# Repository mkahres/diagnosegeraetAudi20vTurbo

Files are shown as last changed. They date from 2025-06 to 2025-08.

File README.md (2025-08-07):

# Audi 20V Turbo Diagnosegerät (Bosch Motronic)

Das ist ein Diagnosegerät zum selber bauen. Es passt ins Handschuhfach, ist benutzerfreundlich und komplett Open Source. Für genauere Analysen gibts noch ein auf die 10 Sensorwerte angepasstes Auswertungstool dazu.

🔽 [aktuelle ZIP-Datei herunterladen (Version 1.1.2)](https://github.com/mkahres/diagnosegeraetAudi20vTurbo/archive/refs/heads/master.zip)

<table>
  <tr>
    <td></td>
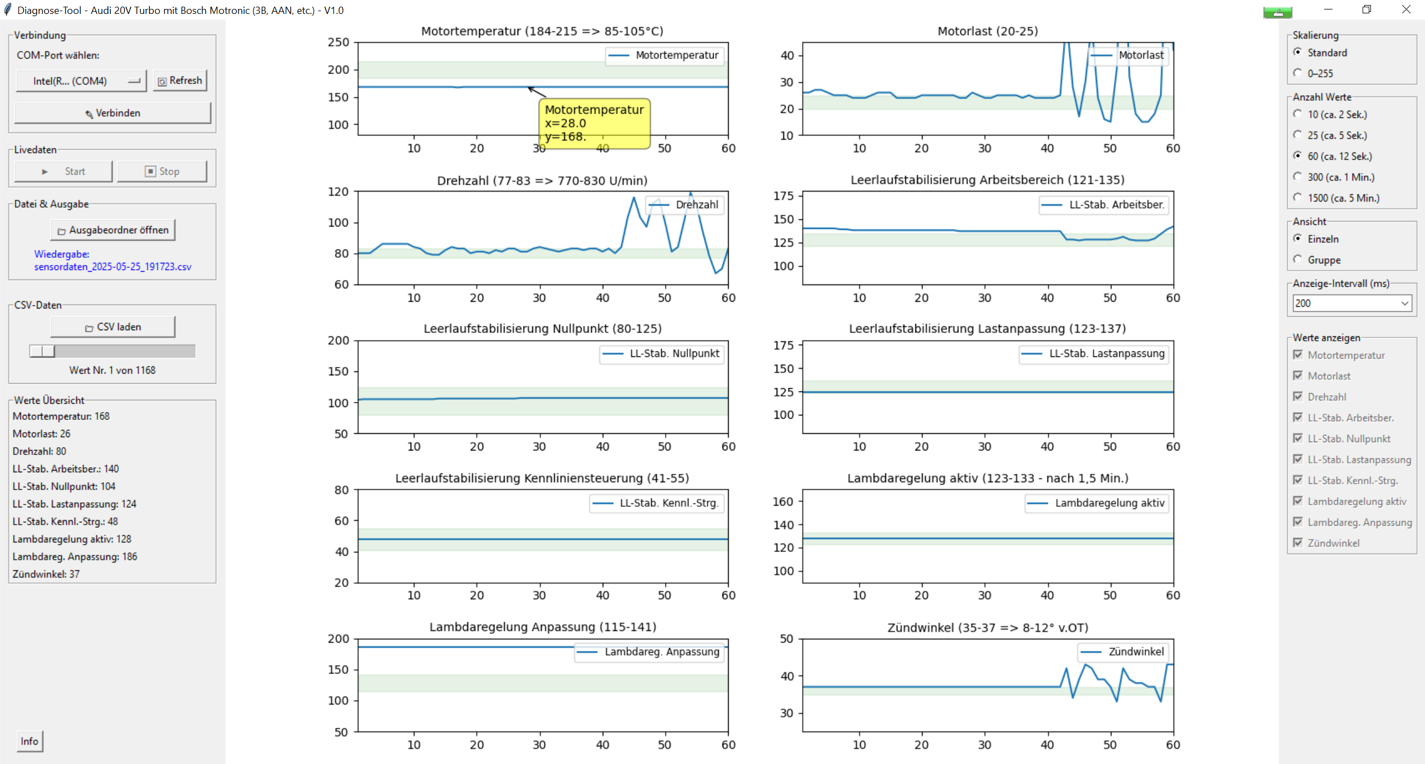
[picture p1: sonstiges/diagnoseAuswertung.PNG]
    <td></td>
  </tr>
</table>

---

## 📲 Bedienung und Infos zum Nachbauen

youtube-Video: [https://www.youtube.com/watch?v=6eNAYaNCjRk](https://www.youtube.com/watch?v=dj4Saa1aYWg)

Bei Fragen kommentiert am besten unter dem Video oder legt hier einen Issue an.

- Gerät startet sobald es am Diagnosestecker am Auto eingesteckt wird (auch ohne Zündung).
- Um die Sensorwerte über das Auswertungsprogramm zu analysieren wird zusätzlich der Laptop per USB an das Diagnosegerät angeschlossen.
- Das Diagnosegerät kann auch allein über USB am Laptop betrieben werden um sich die gespeicherten Fehler/Sensorwerte anzugucken. Das Easteregg funktioniert auch über USB.
- ⚠️ Auf keinen Fall das Gerät an den Diagnosestecker und zusätzlich am Zigarettenanzünder per USB-Adapter anschließen, evtl. gibt es dann ein Masse-Problem!?
- ⚠️ Das Auswertungstool wurde nur auf Laptops mit Windows 10 und 11 getestet. Um es auf Mac/Linux zum Laufen zu bringen sollte man sich schon etwas mit Python auskennen!

---

## 🔧 Funktionen

- ✅ **Fehlerspeicher auslesen über K-Line**
- ✅ **Fehlerspeicher ausblinken**
- ✅ **Fehlerspeicher löschen über K-Line oder am Ende der Blinkcode-Stellglieddiagnose**
- ✅ **Stellglieddiagnose über K-Line**
- ✅ **Stellglieddiagnose mit Blinkcode**
- ✅ **Sensorwerte live auslesen**
- ✅ **Speichern & Laden von Sensordaten und Fehlerspeicher**
- ✅ **Stromversorgung über Diagnosestecker im Auto**
- ✅ **Das zusätzliche Auswertungstool erlaubt genauere Betrachtung der Diagnosewerte über Laptop**
- 🐣 **Easteregg inklusive 😎**

---

## 🚗 Unterstützte Fahrzeuge

Ich habe es nur an meinem Audi 200 20V getestet, daher keine Garantie! Da sich die Steuergeräte nach meinem Kenntnisstand in Bezug auf die Auslesefunktionen bei diesen Motoren nicht unterscheiden, dürfte es bei folgenden Fahrzeugen problemlos funktionieren:
- **Audi 200 20V (3B)**
- **Audi S2 (3B)**
- **Audi S4 / S6 C4 (AAN)**
- **Audi Urquattro 20V (RR)**

vermutlich eingeschränkt verwendbar:
- **20V Turbos mit ABY, ADU, etc.:**
Hier können wohl mehr als 10 Sensoren ausgelesen werden. Dies ist mit dem Tool aktuell nicht möglich. Falls jemand Bock hat, die verwendete Library KLineKWP1281Lib unterstützt das Auslesen sämtlicher Gruppen. Es wäre also theoretisch möglich das Tool zu erweitern. Evtl. gibt es bei den Motoren auch mehr Fehlercodes und andere Fehlertexte.

mit kleinen Änderungen verwendbar:
- **Audi 100/200 (NF/MC und andere):**
bei den Motoren die nur das Ausblinken unterstützen muss die Hardware etwas geändert werden. Außerdem sind kleine Anpassungen in der Software-Konfiguration notwendig (siehe [Anmerkungen](#-anmerkungen))

---

## ⚡ Schaltplan

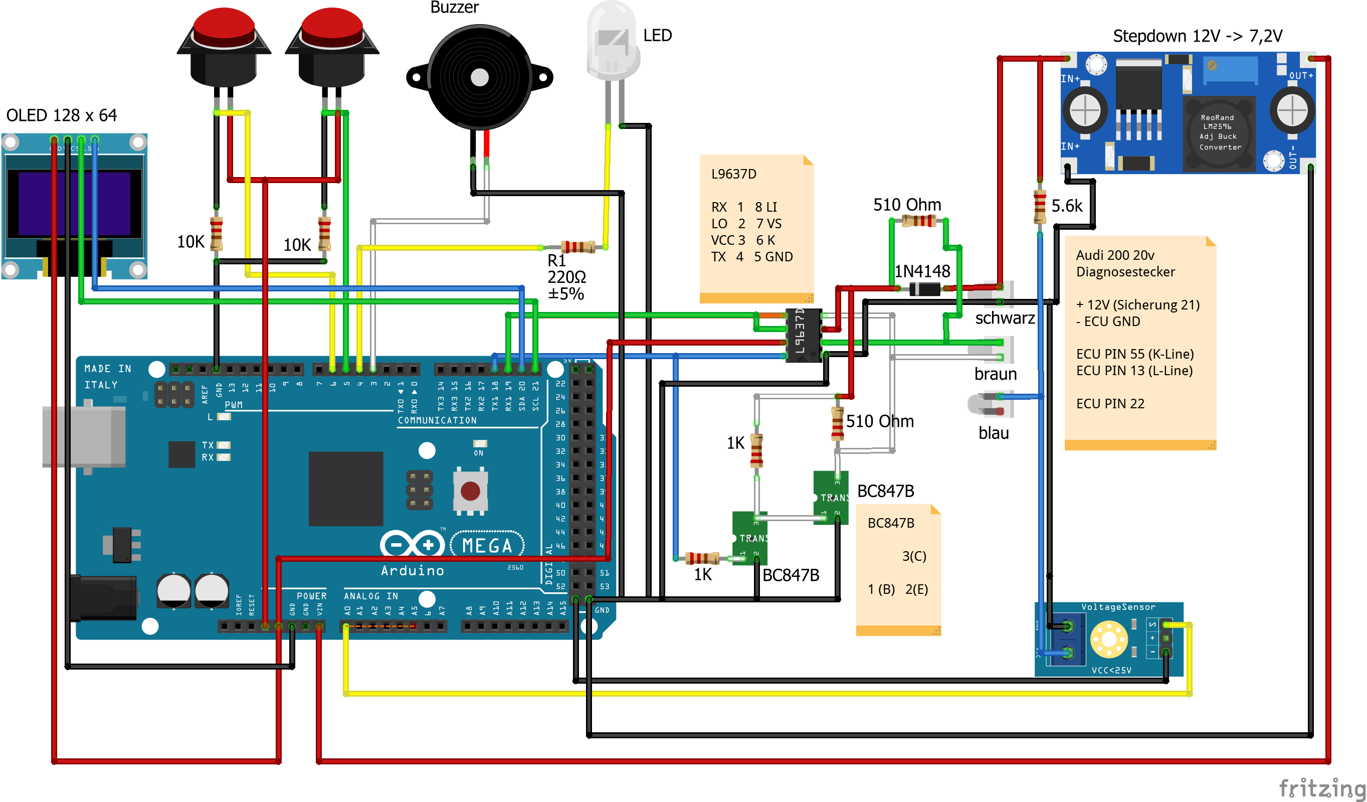
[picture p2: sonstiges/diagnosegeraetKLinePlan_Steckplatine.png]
Schaltplan Vorschau


Unter /sonstiges findet man ein paar Bilder vom Zusammenbau.

---

## 🧱 3D Druck

Den 3D-Druck sollte man am besten mit PETG machen, da es im Hochsommer evtl. doch mal über 60 Grad im Auto werden können und PLA dann schmilzt. Die Dateien liegen unter /stl 

---

## 🖥️ Setup & Upload

Alles nur auf Windows getestet. Gerade das Python Tool könnte auf Mac und Linux Probleme machen!

**Arduino**
- aktuelle Arduino IDE installieren: https://www.arduino.cc/en/software/
- den Sketch (/diagnoseGeraet/diagnoseGeraet.ino) in der IDE öffnen
- folgende Libraries über den Library Manager installieren (https://docs.arduino.cc/software/ide-v1/tutorials/installing-libraries/#using-the-library-manager):
   - Adafruit_SH110X
   - U8g2_for_Adafruit_GFX
- die Library KLineKWP1281Lib von dieser Seite herunterladen (unter Getting started - latest Release) https://github.com/domnulvlad/KLineKWP1281Lib/tree/main und als ZIP-Library einbinden (siehe hier: https://docs.arduino.cc/software/ide-v1/tutorials/installing-libraries/#importing-a-zip-library)
- Board und Port auswählen und den Sketch über den Upload-Button auf den Arduino laden (https://support.arduino.cc/hc/en-us/articles/4733418441116-Upload-a-sketch-in-Arduino-IDE)

**Python**  
- aktuelles Python Release installieren für das Auswertungs-Tool: https://www.python.org/downloads/
- Während der Installation wird gefragt ob man Python zum PATH hinzufügen will, das sollte man tun.
- Falls Microsoft Visual C++ Redistributable noch nicht installiert ist, bitte ebenfalls installieren:
  - https://learn.microsoft.com/de-de/cpp/windows/latest-supported-vc-redist?view=msvc-170
  - https://aka.ms/vs/17/release/vc_redist.x64.exe
  - https://aka.ms/vs/17/release/vc_redist.x86.exe
- Doppelklick auf /diagnoseAuswertung/startTool_Windows.bat zum Starten des Tools

---

## 🛒 Einkaufsliste

- Arduino Mega oder Clone (hier wurde ein Elegoo Mega verwendet)
- L9637D I/O-Controller-IC-Interface
- 1,3 Zoll OLED Display (mit 0,96 Zoll funktioniert der Code nicht, da das eine andere Library benötigt!)
- 2x Diagnose Adapterkabel 2x2 OBD
- 5-adriges Kabel vom Diagnosestecker zum Tool
- 2x JST SM Stecker für Verbindung Adapterkabel -> 5-adriges Kabel -> Arduino
- Gummitülle für das Kabel das ins Gehäuse geht
- LM2596S Step Down Converter
- Spannungssensor DC 0~25V
- LED ⌀ 3mm
- 2x Push Button 12mm mit Mutter
- passiver Buzzer
- 2x Widerstand 510 Ω (L9637d Spezifikation - bitte genau daran halten)
- 2x Widerstand 1K Ω
- 2x Widerstand 10K Ω
- 1x Widerstand 5.6k Ω
- 1x Widerstand 220 Ω
- Diode 1N4148
- 2x Transistor BC847B
- viele Jumperkabel und -stecker
  
Folgende Teile fand ich hilfreich, damit passt dann alles in das kleine Gehäuse rein.
- SOT23 Adapterplatine (für die Transistoren)
- Adafruit SMT Breakout Leiterplatte für SOIC-8 (für den L9637D)
- EPLZON Prototype Board 2 x 1,5 Zoll (da hab ich dann die Platinen, die Widerstände und die Diode draufgelötet)

Für Fahrzeuge die nur das Ausblinken unterstützen braucht man anstatt des L9637D, den Transistoren, Widerständen usw. nur ein Relais
- z.B. AZDelivery KY-019

---

## 📌 Anmerkungen

**Ausblinken mit Relais für NF, MC etc.** 

Für Motoren ohne K-Line Schnittstelle die nur Ausblinken unterstützen muss statt des L9637D ein Relais verwendet werden um die Drahtbrücke zu schließen. Die Verkabelung für den Spannungsmesser um die Blinkcodes zu erkennen muss dann auch geändert werden. 
Fehlercodes und -texte sind für NF und MC bereits im Code hinterlegt. Man muss nur die Konfiguration in der Datei "Constants.h" anpassen:

<pre>const char ENGINE = "3B"; //mögliche Werte: "3B", "MC", "NF"  - für RR, AAN, etc. verwende "3B"
#define USE_RELAIS false //für MC, NF, etc. auf true setzen
#define PIN_RELAY 12 //für MC, NF, etc. den Relais PIN setzen</pre>

**Ausblinken beim 20v Turbo**

Die Ausblinkfunktion wird beim 20v Turbo über den L9637D gesteuert. Theoretisch ist das Ausblinken für den 20V gar nicht notwendig, da alle Funktionen über K-Line verfügbar sind. Wenn man darauf verzichten will kann man folgende Teile weglassen:
- Spannungsmesser
- von den Diagnoseadapter-Kabeln 2x2 braucht man nur noch einen Satz, da dann der blaue Stecker nicht mehr verwendet wird  
- LED weglassen oder besser immer auf an setzen. Dazu in diagnoseGeraetAudi200.ino irgendwo in der Funktion setup() diese Zeile hinzufügen: <pre>analogWrite(ledPin, 5);</pre>

**Debugging** 

Sollte es Probleme bei der K-Line Kommunikation geben kann man in configuration.h das Debugging aktivieren (beide Werte auf "true"). Das sollte man nur zum Testen einschalten, da die Debugging-Ausgaben die Kommunikation mit dem Auswertungstool behindern.

<pre>// Enable/disable printing library debug information on the Serial Monitor.
// You may change the debug level in "KLineKWP1281Lib.h".
#define debug_info false
// Enable/disable printing bus traffic on the Serial Monitor.
#define debug_traffic false</pre>

**Stromversorgung**

Die Versorgung erfolgt über einen Step-Down-Regler, der auf 7,2 V eingestellt ist. Am VIN-Pin des Arduino übernimmt der interne Spannungsregler die Absenkung auf 5 V. Damit dieser zuverlässig arbeitet, sollten mindestens 7 V anliegen. Während das Original (7–12 V) stabil läuft, lieferte ein Elegoo-Clone bei 9 V Eingang ca. 6 V am 5 V-Pin. Mit 7,2 V bekommt man aber dann sichere 5 V.

---

## 📦 Inhalte hier auf GitHub

- `diagnoseGeraet/` → Arduino-Sketch zum Upload auf den Arduino
- `diagnoseAuswertung/` → Python-Tool zur Anzeige und Speicherung von Sensorwerten (Live & CSV)
- `sonstiges/` → Fritzing-Schaltplan und Bilder 
- `stl/` → Dateien für den 3D-Druck

---

## ⚠️ Haftungsausschluss

Dieses Projekt wird ohne jegliche Garantie zur Verfügung gestellt. Die Nutzung erfolgt auf eigene Gefahr. Der Autor übernimmt keine Haftung für Schäden an Fahrzeugen, Steuergeräten oder anderen Komponenten, die durch den Einsatz der bereitgestellten Hardware oder Software entstehen können.

---

## 👍 Danke!

- https://www.blafusel.de/obd/obd2_kw1281.html#5 (sehr gute Beschreibung der K-Line Kommunikation)
- https://github.com/domnulvlad/KLineKWP1281Lib/tree/main (sehr gute Library, damit konnte ich alle Funktionen umsetzen)
- https://www.drive2.ru/c/2032328 (ein Teil des Schaltplans stammt von dieser Seite)
- http://www.audinarren.de/rep-Anleitung/fehlerspeicher.htm (Fehlertexte in Kurz- und Langform)
- http://www.sjmautotechnik.com/trouble_shooting/20vpin.html (viele Infos incl. Pin-Belegung)
- Scheiß-KI die besser mit Python programmieren kann als ich
- und vielen Dank an die Forumsmitglieder von [forum.group44.de ](https://forum.group44.de/), vor allem an BAUM4477 für die ganzen hilfreichen Tipps!
---

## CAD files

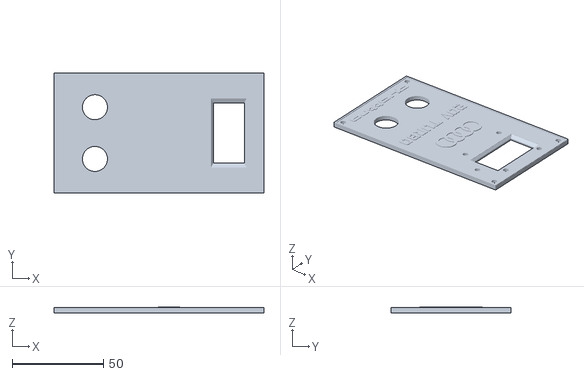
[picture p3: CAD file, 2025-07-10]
stl/Deckel_20v_Turbo.stl
115.1 x 66.0 x 3.20

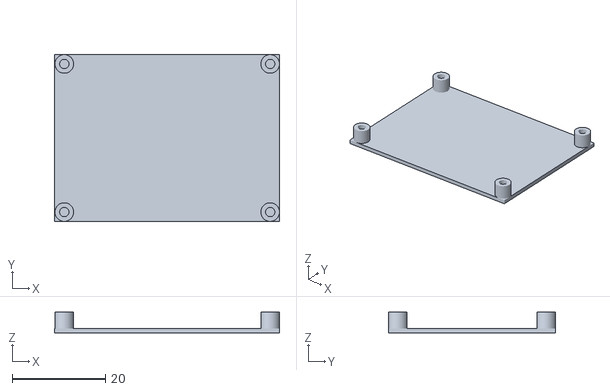
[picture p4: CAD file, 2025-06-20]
stl/Halterung_PrototypeBoard.stl
48.3 x 35.9 x 4.50

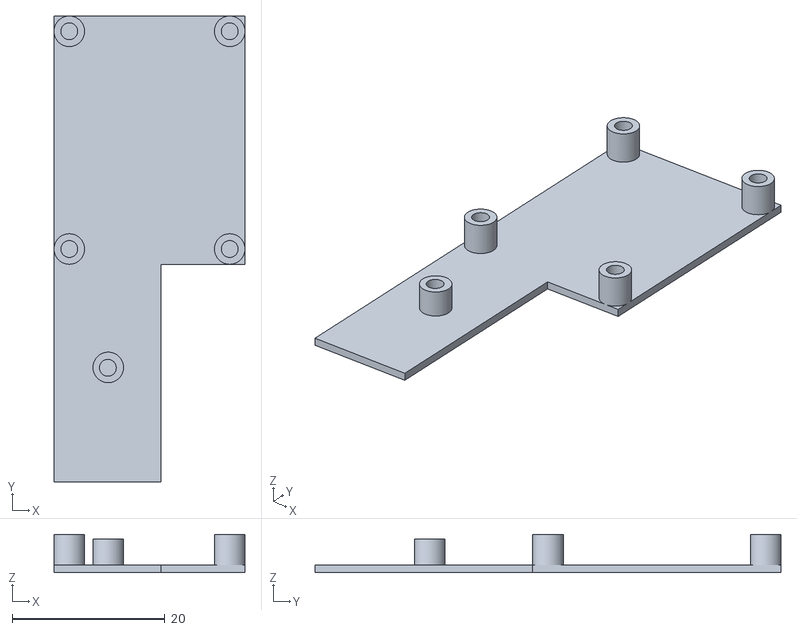
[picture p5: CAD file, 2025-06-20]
stl/Halterung_Spannungssensor_und_Relais.stl
25.0 x 61.0 x 5.00

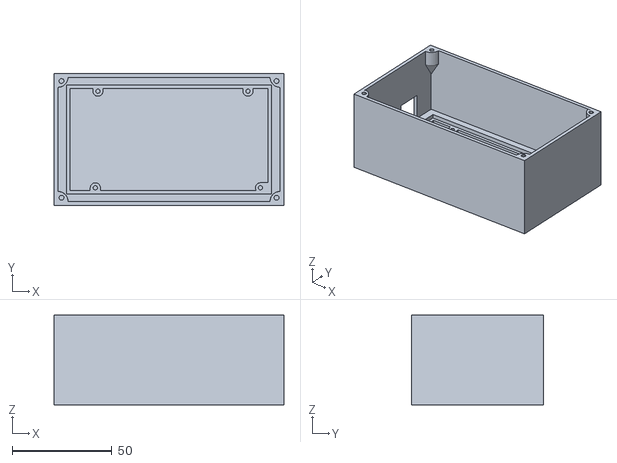
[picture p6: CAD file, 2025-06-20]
stl/Gehaeuse.stl
115.0 x 66.0 x 44.9

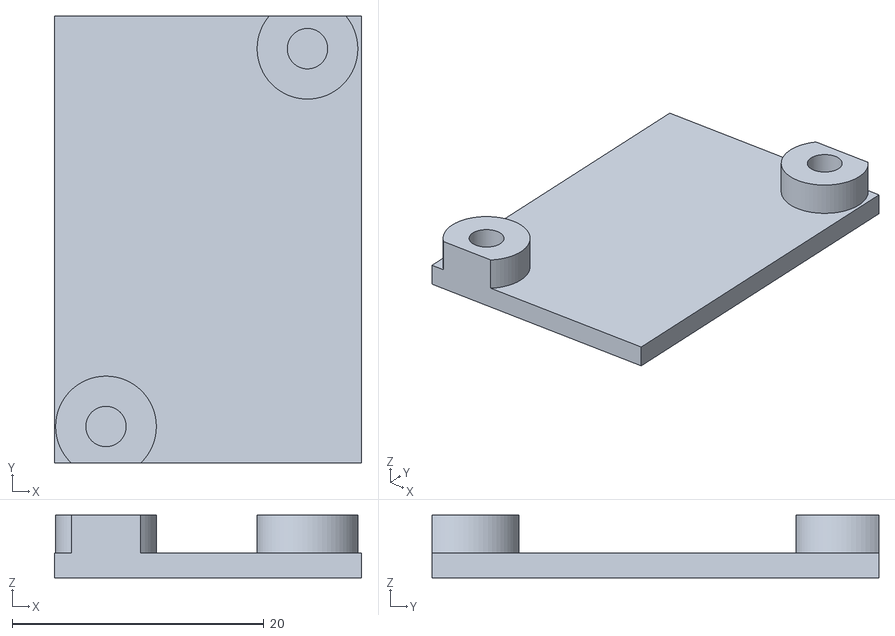
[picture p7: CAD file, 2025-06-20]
stl/Halterung_LM2596S.stl
24.4 x 35.5 x 5.00

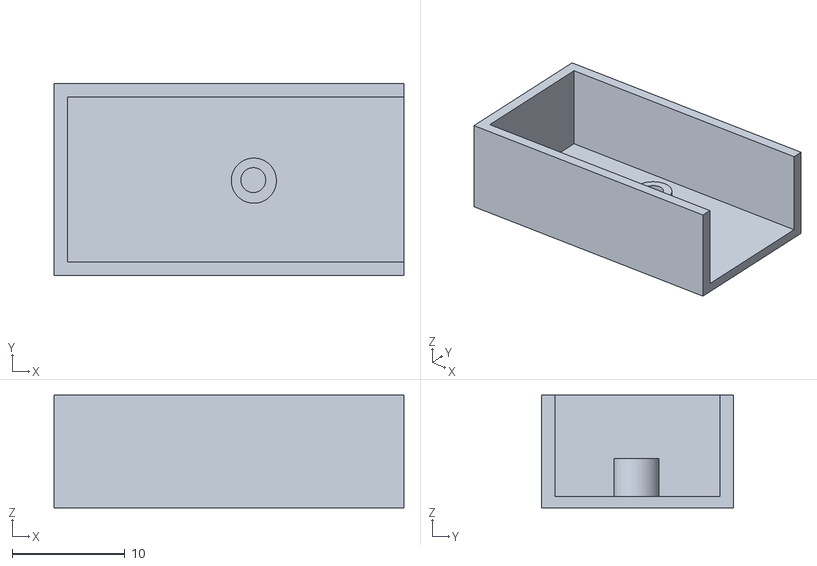
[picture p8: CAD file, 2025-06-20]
stl/Halterung_Spannungssensor.stl
31.0 x 17.0 x 10.00

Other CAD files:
stl/Deckel_200_20v.stl

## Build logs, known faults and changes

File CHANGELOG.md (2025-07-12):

# Changelog

## [1.1.2] – 2025-07-12
- Auswertungstool nun auch mit Windows 11 kompatibel
  
## [1.1.1] – 2025-07-10
- STL für alternativen Deckel (20v Turbo) hinzugefügt
- bessere Bilder vom Inneren des Geräts
- Fehler bei Motorkonfiguration behoben
- Fehler bei wiederholtem Fehlerspeicher ausblinken behoben
  
## [1.1.0] – 2025-07-07
- neue Funktion: optionales Fehlerspeicher löschen am Ende der Stellglieddiagnose per Blinkcode
  
## [1.0.1] – 2025-07-04
- Fehler im Schaltplan korrigiert. Der 1k Widerstand zum zweiten Transistor war falsch verdrahtet.

## [1.0.0] – 2025-06-20
- Erstveröffentlichung

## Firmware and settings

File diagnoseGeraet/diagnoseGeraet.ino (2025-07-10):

#include "Constants.h"
#include "configuration.h"
#include "DisplayManager.h"
#include "MusicManager.h"
#include "MemoryManager.h"
#include "KLineManager.h"
#include "ErrorManager.h"
#include "CrashyBird.h"

DisplayManager displayManager;
MusicManager musicManager;
MemoryManager memoryManager;
KLineManager kLineManager;
ErrorManager errorManager;
CrashyBird crashyBird;

//for memory check
#ifdef __arm__
// should use uinstd.h to define sbrk but Due causes a conflict
extern "C" char* sbrk(int incr);
#else  // __ARM__
extern char *__brkval;
#endif  // __arm__

Adafruit_SH1106G display(SCREEN_WIDTH, SCREEN_HEIGHT, &Wire, OLED_RESET);
U8G2_FOR_ADAFRUIT_GFX u8g2_for_adafruit_gfx;

long currentMillis = 0;
long measureTime = 0;
int voltageBoundary = 7;
boolean isBlinking = false;
long lastBlinkingChange = 0;
long lastInterval = 0;
long voltageTime = 0;

uint8_t START_SCREEN = 0;
uint8_t SELECT_OPERATION = 1;
uint8_t SELECT_MODE = 2;
uint8_t LOAD_FAULT_MEMORY_FAST = 7;
uint8_t LOAD_FAULT_MEMORY_BLINK = 8;
uint8_t LOAD_SENSOR_DATA = 10;
uint8_t PREPARE_FAULT_MEMORY_FAST = 11;
uint8_t PREPARE_FAULT_MEMORY_BLINK = 12;
uint8_t PREPARE_ACTUATOR_DIAGNOSTICS_1 = 13;
uint8_t PREPARE_ACTUATOR_DIAGNOSTICS_2 = 14;
uint8_t EXECUTE_FAULT_MEMORY_FAST = 15;
uint8_t EXECUTE_FAULT_MEMORY_BLINK = 16;
uint8_t ANALYZE_FAULT_MEMORY_BLINK = 17;
uint8_t EXECUTE_ACTUATOR_DIAGNOSTICS = 18;
uint8_t ANALYZE_ACTUATOR_DIAGNOSTICS = 19;
uint8_t EXECUTE_SENSOR_DATA = 20;
uint8_t SHOW_FAULT_MEMORY = 21;
uint8_t SHOW_SENSOR_DATA_TEMP = 22;
uint8_t SHOW_SENSOR_DATA_FINAL = 23;
uint8_t DELETE_FAULT_MEMORY_FAST = 24;
uint8_t ANALYZE_ACTUATOR_FINISHED = 25;
uint8_t ANALYZE_ACTUATOR_NOT_POSSIBLE = 26;
uint8_t ANALYZE_FAULT_MEMORY_NOT_POSSIBLE = 27;
uint8_t DATA_TO_SERIAL = 28;
uint8_t SELECT_OPERATION_BLINK = 29;
uint8_t PREPARE_ACTUATOR_DIAGNOSTICS_KLINE = 30;
uint8_t EXECUTE_ACTUATOR_DIAGNOSTICS_KLINE = 31;
uint8_t ANALYZE_ACTUATOR_DELETE_FAULTS = 32;
uint8_t CRASHY_BIRD = 99;

uint8_t phase = START_SCREEN;

#define MAX_SENSORS 10
int sensorData[MAX_SENSORS];
size_t sensorCount = 0;

int indexSensorData = 0;

#define MAX_FAULTS 20
int faultMemory[MAX_FAULTS];
size_t faultCount = 0;
int indexFaultMemory = 0;
int faultsVAGCodes[MAX_FAULTS];
int codeCount = 0;

unsigned long lastChangeTime = 0;
boolean lastState = false;
int codeForDisplay;
int codeActuator = -1;
int counter2500ms = 0;

int blinkCount = 0;
int digitIndex = 0;
int digits[4] = {0, 0, 0, 0};
boolean ignoreFirstLongBreak = true;
boolean faultMemoryBlinkFinished = false;
boolean actuatorBlinkFinished = false;
char displayBufferBlink[8] = "?-?-?-?";
char bufferCode[10];
char* unknownCode = "?-?-?-?";
boolean noBlinkingFor12Seconds = false;

ErrorStructure errorStructure;
ErrorStructure errorStructureEmpty;

boolean newPhase = false;
boolean buttonLeftPressed = false;
boolean buttonRightPressed = false;

const int ledPin = 4; 

const char* programTypes[] = {"Fehlerspeicher", "Sensordaten", "Stellglieddiagnose", "Ausblinken"};
const char* programTypesBlink[] = {"Fehlerspeicher ausblinken", "Stellglieddiagnose (blink)"};
int programTypeIndex = 0;
int programTypeIndexBlink = 0;
bool blinkingOperation = false;

const char* programModes[] = {"Ausführen", "Letztes Ergebnis"};
const char* programModesOnlyExecute[] = {"Ausführen"};
const char* programModesWithDelete[] = {"Ausführen", "Letztes Ergebnis", "Ecu-Speicher löschen"};
int programModeIndex = 0;

boolean bothButtonsPressed = false;

char inputStringPython[32];  
byte inputIndex = 0;
bool stringPythonCommandComplete = false;
bool isSendingToPython = false;     
unsigned long sendIntervalTestdaten = 200; 
unsigned long lastSendTimeTestdaten = 0;

void setup(void) 
{   
  Serial.begin (115200);

  pinMode(PIN_RELAY, OUTPUT);
  pinMode(TX_pin, OUTPUT);
  setPinState(HIGH);

  display.begin(I2C_ADDRESS, true);
  display.clearDisplay();
  display.setTextSize(1);
  display.setTextColor(SH110X_WHITE);
  display.setTextWrap(false);
  
  u8g2_for_adafruit_gfx.begin(display);  

  errorStructureEmpty.shortText[0] = '\0'; 
  
  randomSeed(analogRead(0));

  Serial.println("READY");
} 

void loop(void)
{  
       
      currentMillis = millis();

      if(phase != CRASHY_BIRD)
      {
        //auf Python Programm reagieren
        while (Serial.available()) {
          char inChar = (char)Serial.read();

          if (inChar == '>') {
            inputStringPython[inputIndex++] = inChar;
            inputStringPython[inputIndex] = '\0';  // Null-terminieren
            stringPythonCommandComplete = true;
          }
          else if (inputIndex < sizeof(inputStringPython) - 1) {
            inputStringPython[inputIndex++] = inChar;
          }
          else {
            // Zu lang -> zurücksetzen
            inputIndex = 0;
            inputStringPython[0] = '\0';
          }
        }
      }
      if (stringPythonCommandComplete) {
        handlePythonCommand(inputStringPython);  // C-String Übergabe
        inputStringPython[0] = '\0';             // Zurücksetzen
        inputIndex = 0;
        stringPythonCommandComplete = false;
      }
      if(phase == DATA_TO_SERIAL)
      {
        if(isSendingToPython)
        {
          sendSensorDataViaSerial();
        }
      }
      // zum Testen
      /*
      if (isSendingToPython && currentMillis - lastSendTimeTestdaten >= sendIntervalTestdaten) 
      {
        lastSendTimeTestdaten = currentMillis;
        sendeZufallswerte();
      }    
      */
      else if(phase == START_SCREEN)
      {
        displayManager.displayStartScreen(display, u8g2_for_adafruit_gfx);
        musicManager.playStarWars();        
        phase = SELECT_OPERATION;   
      }
      else if(phase == CRASHY_BIRD)
      {
        bothButtonsPressed = false;
        crashyBird.crashyBird(display, u8g2_for_adafruit_gfx);
        if(digitalRead(BUTTON_LEFT_PIN) == HIGH && digitalRead(BUTTON_RIGHT_PIN) == HIGH) 
        {
          if(!bothButtonsPressed)
          {
            bothButtonsPressed = true;
            phase = SELECT_OPERATION;
            delay(1000);
          }
          else
          {
            bothButtonsPressed = false;
          }          
        }        
      }
      else if(phase == SELECT_OPERATION)
      {
        if(digitalRead(BUTTON_LEFT_PIN) == HIGH && digitalRead(BUTTON_RIGHT_PIN) == HIGH) 
        {
          if(!bothButtonsPressed)
          {
            bothButtonsPressed = true;
            phase = CRASHY_BIRD;
          }
          else
          {
            bothButtonsPressed = false;
          }          
        }
        else
        {
          if (digitalRead(BUTTON_LEFT_PIN) == HIGH) 
          { 
            if (!buttonLeftPressed) 
            { 
              tone(BUZZER, NOTE_D5, 200);
              buttonLeftPressed = true;
              programTypeIndex = (programTypeIndex + 1) % 4;
            }
          } 
          else 
          {
            buttonLeftPressed = false; 
          }
          if(programTypeIndex == 3)
          {
            manageRightButtonForNextPhase(SELECT_OPERATION_BLINK);
          }
          else
          {
            manageRightButtonForNextPhase(SELECT_MODE);
          }          
          displayManager.displayProgramTypeChoice(display, u8g2_for_adafruit_gfx, programTypes, programTypeIndex, blinkingOperation);
        }
      }    
      else if(phase == SELECT_OPERATION_BLINK)
      {
        if (digitalRead(BUTTON_LEFT_PIN) == HIGH) 
        { 
          if (!buttonLeftPressed) 
          { 
            tone(BUZZER, NOTE_D5, 200);
            buttonLeftPressed = true;
            programTypeIndexBlink = (programTypeIndexBlink + 1) % 2;
          }
        } 
        else 
        {
          buttonLeftPressed = false; 
        }
        manageRightButtonForNextPhase(SELECT_MODE);
        displayManager.displayProgramTypeChoice(display, u8g2_for_adafruit_gfx, programTypesBlink, programTypeIndexBlink, blinkingOperation);
      }         
      else if(phase == SELECT_MODE)
      {
        if (digitalRead(BUTTON_LEFT_PIN) == HIGH) 
        { 
          if (!buttonLeftPressed) 
          { 
            tone(BUZZER, NOTE_D5, 200);
            buttonLeftPressed = true;
            if(!blinkingOperation && programTypeIndex == 0)
            {
              programModeIndex = (programModeIndex + 1) % 3;
            }
            else if(!blinkingOperation && programTypeIndex == 2)
            {
              programModeIndex = (programModeIndex + 1) % 1;
            }
            else if(!blinkingOperation)
            {
              programModeIndex = (programModeIndex + 1) % 2;
            }
            else if(blinkingOperation && programTypeIndexBlink == 0)
            {
              programModeIndex = (programModeIndex + 1) % 2;
            }
            else if(blinkingOperation && programTypeIndexBlink == 1)
            {
              programModeIndex = (programModeIndex + 1) % 1;
            }           
          }
        } 
        else 
        {
          buttonLeftPressed = false; 
        }

        if (digitalRead(BUTTON_RIGHT_PIN) == HIGH) 
        { 
          if (!buttonRightPressed) 
          { 
            tone(BUZZER, NOTE_E5, 200);
            buttonRightPressed = true;

            if(blinkingOperation)
            {
              if(programModeIndex == 0)
              {
                if(programTypeIndexBlink == 0) { phase = PREPARE_FAULT_MEMORY_BLINK; }
                else if(programTypeIndexBlink == 1) { phase = PREPARE_ACTUATOR_DIAGNOSTICS_1; }
              }
              else if(programModeIndex == 1)
              {
                if(programTypeIndexBlink == 0) { phase = LOAD_FAULT_MEMORY_BLINK; }
              }
            }            
            else
            {
              if(programModeIndex == 0)
              {
                if(programTypeIndex == 0) { phase = PREPARE_FAULT_MEMORY_FAST; }
                else if(programTypeIndex == 1) { phase = EXECUTE_SENSOR_DATA; }
                else if(programTypeIndex == 2) { phase = PREPARE_ACTUATOR_DIAGNOSTICS_KLINE; }
              }
              else if(programModeIndex == 1)
              {
                if(programTypeIndex == 0) { phase = LOAD_FAULT_MEMORY_FAST; }
                else if(programTypeIndex == 1) { phase = LOAD_SENSOR_DATA; }
              }
              else if(programModeIndex == 2)
              {
                if(programTypeIndex == 0) { phase = DELETE_FAULT_MEMORY_FAST; }
              }
            }
            newPhase = true;
          }
        } 
        else 
        {
          buttonRightPressed = false; 
        }
        if(!blinkingOperation && programTypeIndex == 0)
        {
          displayManager.displayProgramModeChoice(display, u8g2_for_adafruit_gfx, programModesWithDelete, programModeIndex, programTypes[programTypeIndex], programTypeIndex, blinkingOperation);
        }
        else if(!blinkingOperation && programTypeIndex == 2)
        {
          displayManager.displayProgramModeChoice(display, u8g2_for_adafruit_gfx, programModesOnlyExecute, programModeIndex, programTypes[programTypeIndex], programTypeIndex, blinkingOperation);
        }
        else if(!blinkingOperation) 
        {
          displayManager.displayProgramModeChoice(display, u8g2_for_adafruit_gfx, programModes, programModeIndex, programTypes[programTypeIndex], programTypeIndex, blinkingOperation);
        }
        else if(blinkingOperation && programTypeIndexBlink == 0)
        {
          displayManager.displayProgramModeChoice(display, u8g2_for_adafruit_gfx, programModes, programModeIndex, programTypesBlink[programTypeIndexBlink], programTypeIndexBlink, blinkingOperation);
        }
        else if(blinkingOperation && programTypeIndexBlink == 1)
        {
          displayManager.displayProgramModeChoice(display, u8g2_for_adafruit_gfx, programModesOnlyExecute, programModeIndex, programTypesBlink[programTypeIndexBlink], programTypeIndexBlink, blinkingOperation);
        }        
      }     
      //Laden
      else if(phase == LOAD_FAULT_MEMORY_FAST)
      {
        memoryManager.loadFaultMemoryFast(faultMemory, MAX_FAULTS, faultCount);
        phase = SHOW_FAULT_MEMORY;
        displayManager.initFaultMemoryDetails();
      }
      else if(phase == LOAD_SENSOR_DATA)
      {
        memoryManager.loadSensorData(sensorData, MAX_SENSORS, sensorCount);
        phase = SHOW_SENSOR_DATA_FINAL;
      } 
      else if(phase == LOAD_FAULT_MEMORY_BLINK)
      {
        memoryManager.loadFaultMemoryBlink(faultMemory, MAX_FAULTS, faultCount);
        phase = SHOW_FAULT_MEMORY;
        displayManager.initFaultMemoryDetails();
      }      
      //Anzeigen
      else if(phase == SHOW_SENSOR_DATA_FINAL)
      {
        if (digitalRead(BUTTON_RIGHT_PIN) == HIGH) 
        { 
          if (!buttonRightPressed) 
          { 
            tone(BUZZER, NOTE_E5, 200);
            buttonRightPressed = true;
                        
            indexSensorData ++;
            if(indexSensorData > 10)
            {
              indexSensorData = 0;
            }
          }
        } 
        else 
        {
          buttonRightPressed = false; 
        }
        if(indexSensorData == 0)
        {
          displayManager.displaySensorDataFinal(display, u8g2_for_adafruit_gfx, sensorData, false);
        }
        else
        {
          displayManager.displaySensorDetails(display, u8g2_for_adafruit_gfx, indexSensorData, sensorData[indexSensorData-1]);
        }        
        manageLeftButtonForMenu(false);
      }   
      else if(phase == SHOW_FAULT_MEMORY)
      {
        if (digitalRead(BUTTON_RIGHT_PIN) == HIGH) 
        { 
          if (!buttonRightPressed) 
          { 
            displayManager.initFaultMemoryDetails();
            tone(BUZZER, NOTE_E5, 200);
            buttonRightPressed = true;
                        
            indexFaultMemory ++;
            if(indexFaultMemory > faultCount)
            {
              indexFaultMemory = 0;
            }
          }
        } 
        else 
        {
          buttonRightPressed = false; 
        }
        if(indexFaultMemory == 0)
        {
          displayManager.displayFaultMemoryOverview(display, u8g2_for_adafruit_gfx, faultMemory, faultCount);
        }
        else
        {       
          displayManager.displayFaultMemoryDetails(display, u8g2_for_adafruit_gfx, faultMemory[indexFaultMemory-1], faultCount, indexFaultMemory, errorManager);
        }
        
        manageLeftButtonForMenu(false);
      }   
     
      //Ausführen
      else if(phase == PREPARE_FAULT_MEMORY_FAST)
      {
        displayManager.prepareFaultMemory(display, u8g2_for_adafruit_gfx, false);       
        manageLeftButtonForMenu(false);
        manageRightButtonForNextPhase(EXECUTE_FAULT_MEMORY_FAST);      
      }    
      else if(phase == EXECUTE_FAULT_MEMORY_FAST)
      {
        if(newPhase)
        {
          displayManager.showLoadFaultMemory(display, u8g2_for_adafruit_gfx);
          newPhase = false;
          kLineManager.connect();
          kLineManager.getFaultMemory(display, u8g2_for_adafruit_gfx, displayManager, faultsVAGCodes, MAX_FAULTS, faultCount);
          for(int i = 0; i < faultCount; i++)
          {
            faultMemory[i] = errorManager.findCodeByVAGCode(faultsVAGCodes[i]);
          }
          memoryManager.saveFaultMemoryFast(faultMemory, faultCount);
          phase = LOAD_FAULT_MEMORY_FAST;
        }
      }      
      else if(phase == DELETE_FAULT_MEMORY_FAST)
      {
        displayManager.showDeleteFaultMemory(display, u8g2_for_adafruit_gfx);
        kLineManager.clearFaultMemory();
        goToMenu();
      }
      else if(phase == EXECUTE_SENSOR_DATA)
      {
        if(newPhase)
        {
          displayManager.showLoadSensorData(display, u8g2_for_adafruit_gfx);
          newPhase = false;
          kLineManager.connect();
        }
        else
        {
          kLineManager.getSensorData(display, u8g2_for_adafruit_gfx, displayManager, sensorData, MAX_SENSORS, sensorCount); 
          displayManager.displaySensorDataFinal(display, u8g2_for_adafruit_gfx, sensorData, true);
        }
        manageLeftButtonForMenu(true);
       
        if (digitalRead(BUTTON_RIGHT_PIN) == HIGH) 
        { 
          if (!buttonRightPressed) 
          { 
            tone(BUZZER, NOTE_E5, 200);
            buttonRightPressed = true;
           
            kLineManager.disconnect();
            memoryManager.saveSensorData(sensorData, 10);
            displayManager.showSaveSensorData(display, u8g2_for_adafruit_gfx);
            delay(2000);
            phase = SHOW_SENSOR_DATA_FINAL;
          }
        } 
        else 
        {
          buttonRightPressed = false; 
        }        
      }        
      else if(phase == PREPARE_ACTUATOR_DIAGNOSTICS_KLINE)
      {
        displayManager.prepareActuatorDiagnostics2(display, u8g2_for_adafruit_gfx);
        manageLeftButtonForMenu(false);
        newPhase = true;
        measureTime = 0;
        manageRightButtonForNextPhase(EXECUTE_ACTUATOR_DIAGNOSTICS_KLINE);      
      } 
      else if(phase == EXECUTE_ACTUATOR_DIAGNOSTICS_KLINE)
      {
        if(newPhase)
        {
          displayManager.showWaitingActuatorDiagnostics(display, u8g2_for_adafruit_gfx);
          newPhase = false;
          kLineManager.connect();
          int vagCode = kLineManager.performOutputTests();     
          int errorCode = errorManager.findCodeByVAGCode(vagCode);
          errorStructure = errorManager.findErrorStructureByErrorCode(errorCode, ENGINE);
          sprintf(bufferCode, "%d", errorCode); 
          displayManager.showAnalyzeActuators(display, u8g2_for_adafruit_gfx, bufferCode, errorStructure, true);
          measureTime = currentMillis;
        }
        else
        {
          if(currentMillis > measureTime)
          {            
            kLineManager.update();
            measureTime = currentMillis + 10;
          }
          manageLeftButtonForMenu(false);
          if (digitalRead(BUTTON_RIGHT_PIN) == HIGH) 
          {
            if (!buttonRightPressed) 
            { 
              tone(BUZZER, NOTE_E5, 200);
              buttonRightPressed = true;
              int vagCode = kLineManager.performOutputTests();     
              int errorCode = errorManager.findCodeByVAGCode(vagCode);
              errorStructure = errorManager.findErrorStructureByErrorCode(errorCode, ENGINE);
              sprintf(bufferCode, "%d", errorCode); 
              displayManager.showAnalyzeActuators(display, u8g2_for_adafruit_gfx, bufferCode, errorStructure, true);
            }
          } 
          else 
          {
            buttonRightPressed = false; 
          }        
        
        }
      }             
      else if(phase == PREPARE_ACTUATOR_DIAGNOSTICS_1)
      {
        displayManager.prepareActuatorDiagnostics1(display, u8g2_for_adafruit_gfx);
        manageLeftButtonForMenu(false);
        manageRightButtonForNextPhase(PREPARE_ACTUATOR_DIAGNOSTICS_2);      
      }    
      else if(phase == PREPARE_ACTUATOR_DIAGNOSTICS_2)
      {         
        delay(100);
        if(newPhase)
        {
          displayManager.prepareActuatorDiagnostics2(display, u8g2_for_adafruit_gfx);
          newPhase = false;
          setPinState(LOW);          
        }
        manageLeftButtonForMenu(false);

        if (digitalRead(BUTTON_RIGHT_PIN) == HIGH) 
        {
          if (!buttonRightPressed) 
          { 
            tone(BUZZER, NOTE_E5, 200);
            buttonRightPressed = true;
            measureTime = currentMillis + 4100;
            displayManager.showAnalyzeActuators(display, u8g2_for_adafruit_gfx, displayBufferBlink, errorStructureEmpty, false);
            phase = EXECUTE_ACTUATOR_DIAGNOSTICS;
          }
        } 
        else 
        {
          buttonRightPressed = false; 
        }        
        
      }       
      else if(phase == EXECUTE_ACTUATOR_DIAGNOSTICS)
      {
        if(newPhase)
        {
          newPhase = false;          
          setPinState(LOW);     
        }
        else if(currentMillis > measureTime)
        {
          setPinState(HIGH);  
          measureTime = currentMillis;
          phase = ANALYZE_ACTUATOR_DIAGNOSTICS;
          newPhase = true;
        }
      }
      else if(phase == ANALYZE_ACTUATOR_DIAGNOSTICS)
      {
        if(!actuatorBlinkFinished)
        {
          if(noBlinkingFor12Seconds)
          {          
            phase = ANALYZE_ACTUATOR_NOT_POSSIBLE;
          }
          else
          {
            analyzeActuators(currentMillis);
          }
        }
        else
        {
          phase = ANALYZE_ACTUATOR_DELETE_FAULTS;
        }
        if (digitalRead(BUTTON_RIGHT_PIN) == HIGH) 
        { 
          if (!buttonRightPressed) 
          { 
            resetBlinkVariables(true);
            displayManager.showAnalyzeActuators(display, u8g2_for_adafruit_gfx, unknownCode, errorStructureEmpty, false);
            tone(BUZZER, NOTE_E5, 200);
            buttonRightPressed = true;
            setPinState(LOW);  
            delay(4100);
            setPinState(HIGH);  
          }   
        }
        else 
        {
          buttonRightPressed = false; 
        } 
      }     
      else if(phase == ANALYZE_ACTUATOR_DELETE_FAULTS)
      {
        displayManager.showDeleteFaultMemoryQuestion(display, u8g2_for_adafruit_gfx);
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

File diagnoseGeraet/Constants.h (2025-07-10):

#ifndef Constants_h
#define Constants_h

#include <avr/pgmspace.h>
#include "Arduino.h"
#include <KLineKWP1281Lib.h>
#include <Adafruit_SH110X.h>
#include <U8g2_for_Adafruit_GFX.h>

const char ENGINE[] = "3B"; //mögliche Werte: "3B", "MC", "NF"  - für RR, AAN, etc. verwende "3B"
#define USE_RELAIS false //für MC, NF, etc. auf true setzen
#define PIN_RELAY 12 //für MC, NF, etc. den Relais PIN setzen


#define SCREEN_WIDTH 128
#define SCREEN_HEIGHT 64
#define OLED_RESET -1
#define I2C_ADDRESS 0x3C

#define BUTTON_LEFT_PIN 5
#define BUTTON_RIGHT_PIN 6

//K-Line

// Change which measurement to read, from which group.
#define GROUP_TO_READ 0 // valid range: 0-255
#define INDEX_TO_READ 0 // valid range: 0-3


const char errorNotFound[] PROGMEM =  "Fehlertext nicht gefunden";

const char error_1111_3B[] PROGMEM = "Schaltkreise defekt, falsche Checksumme der EPROMs (je nach Software) -> Masseverbindung und Verdrahtung überprüfen, Steuergerät ersetzen";
const char error_1111_MC[] PROGMEM = "Bauteil defekt -> Steuergerät reparieren bzw. austauschen";
const char error_1111_NF[] PROGMEM = "Motorsteuergerät, oder Zündsteuergerät defekt, bzw schadhaftes Bauteil -> Elektrik überprüfen, Steuergerät reparieren, bzw ersetzen";
const char error_1231_3B_NF[] PROGMEM = "Drehzahlsensor am Getriebe (G68), Drehzahlsignal für Zündsteuergerät (ROV), Sensor überprüfen";
const char error_2111_3B_MC[] PROGMEM = "Fehler kommt immer wenn Motor bei der Fehlerdiagnose aus war! Drehzahlsensor, Leitung unterbrochen, oder Kurzschluss, Geber und/oder Leitung defekt, Schwungradzähne verschmutzt / defekt";
const char error_2112_3B_MC[] PROGMEM = "OT Geber auf dem Schwungrad defekt / fehlt, Bezugsmarkengeber verstellt, Stift auf dem Schwungrad, Hallsensor im Verteiler dejustiert";
const char error_2113_3B_MC[] PROGMEM = "Befestigung des Verteilers, Hallsensor fehlerhaft, Verteiler, bzw Hallgeber lose / falsch befestigt";
const char error_2121_3B[] PROGMEM = "Kontakt öffnet nicht, Drosselklappenschalter defekt, Leitungsunterbrechung, Schalter ersetzen";
const char error_2121_MC[] PROGMEM = "Drosselklappenschalter / Leerlaufkontakt, Kontakt öffnet nicht -> Drosselklappenschalter defekt, Leitungsunterbrechung, Schalter ersetzen";
const char error_2121_NF[] PROGMEM = "Kontakt defekt, öffnet nicht -> Schalter defekt, Befestigung schadhaft, Leitungsunterbrechung";
const char error_2122_NF[] PROGMEM = "Drehzahlsignal für Zündsteuergerät, Unterbrechung, oder Kurzschluss, Sensor, oder Kabel defekt, Zahnkranz auf dem Schwungrad beschädigt";
const char error_2123_MC_NF[] PROGMEM = "Drosselklappenschalter / Volllastkontakt, Kontakt öffnet nicht -> Drosselklappenschalter defekt, Leitungsunterbrechung, Schalter ersetzen";
const char error_2132_3B_NF[] PROGMEM = "Datenübertragung (Abgas) unterbrochen, Leitung überprüfen (California Vehicles only)";
const char error_2141_3B_MC[] PROGMEM = "Motorklopfen, Zündungsspätverstellung um 7,8 grad, Ladedruck reduziert (20 V), Kraftstoff mit zu niedriger Oktanzahl, zu hohe Kompression, Ladedruck zu hoch";
const char error_2141_NF[] PROGMEM = "Regelbereich überschritten, Motorklopfen, max Spätverstellung, Kraftstoff mit zu niedriger Oktanzahl, zu starke Kompression, Verkokung des Brennraums";
const char error_2142_3B[] PROGMEM = "Klopfsensor defekt, Leitung unterbrochen, Klopfsensor / Leitung überprüfen, bzw austauschen - Symptom: Zündung wird auf spät verstellt, hoher Kraftstoffverbrauch, Leistungsverlust, Ladedruck bleibt unter 1,3 bar";
const char error_2142_MC[] PROGMEM = "Sensor defekt, Leitungsunterbrechung, Sensor und Leitung überprüfen - Symptom: Zündspätverstellung, Leistungsverlust, erhöhter Verbrauch";
const char error_2142_NF[] PROGMEM = "Sensor defekt, Leitungsunterbrechung, Sensor und Leitung überprüfen - Symptom: Zündspätverstellung, Leistungsverlust, erhöhter Verbrauch";
const char error_2143_3B[] PROGMEM = "Klopfsensor Nr. 2, (Zylinder 3, 4, 5) Motorklopfen, Zündungsspätverstellung um 7,8 grad, Ladedruck reduziert (20 V), Kraftstoff mit zu niedriger Oktanzahl, zu hohe Kompression, Ladedruck zu hoch";
const char error_2143_MC[] PROGMEM = "Klopfsensor Nr. 2, (Zylinder 3, 4, 5) MC Motor mit 2 Klopfsensoren ab Fg. Nr. KN 038262, Motorklopfen, Zündungsspätverstellung um 7,8 grad. Kraftstoff mit zu niedriger Oktanzahl, zu hohe Kompression, Ladedruck zu hoch";
const char error_2144_3B[] PROGMEM = "Klopfsensor Nr. 2, (Zylinder 3, 4, 5) Klopfsensor defekt, Leitung unterbrochen, Klopfsensor / Leitung überprüfen, bzw austauschen, Symptom: Zündung wird auf spät verstellt, hoher Kraftstoffverbrauch, Leistungsverlust, Ladedruck bleibt unter 1,3 bar";
const char error_2144_MC[] PROGMEM = "Klopfsensor Nr. 2, (Zylinder 3, 4, 5) MC Motor mit 2 Klopfsensoren ab Fg. Nr. KN 038262, Klopfsensor defekt, Leitung unterbrochen, Klopfsensor / Leitung überprüfen, bzw austauschen, Symptom: Zündung wird auf spät verstellt, hoher Kraftstoffverbrauch, Leistungsverlust, Ladedruck bleibt unter 1,3 bar";
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

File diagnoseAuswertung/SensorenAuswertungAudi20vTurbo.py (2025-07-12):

import serial
from serial.tools import list_ports
import csv
import matplotlib.pyplot as plt
from matplotlib.animation import FuncAnimation
from collections import deque
from tkinter import *
from tkinter import filedialog, ttk
import os
from datetime import datetime
import subprocess
import mplcursors
import threading
import time
from tkinter import StringVar
from matplotlib.backends.backend_tkagg import FigureCanvasTkAgg
from tkinter import messagebox

# -------- Konfiguration --------
werte_bereich = [
    (184, 215), (20, 25), (77, 83), (121, 135), (80, 125),
    (123, 137), (41, 55), (123, 133), (115, 141), (35, 37)
]
anzeigebereich = [
    (80, 250), (10, 45), (60, 120), (80, 180), (50, 200),
    (80, 180), (20, 80), (90, 170), (50, 200), (25, 50)
]
bezeichnungen = [
    "Motortemperatur", "Motorlast", "Drehzahl", "LL-Stab. Arbeitsber.",
    "LL-Stab. Nullpunkt", "LL-Stab. Lastanpassung", "LL-Stab. Kennl.-Strg.", "Lambdaregelung aktiv",
    "Lambdareg. Anpassung", "Zündwinkel"
]
bezeichnungen_lang = [
    "Motortemperatur (184-215 => 85-105°C)", "Motorlast (20-25)", "Drehzahl (77-83 => 770-830 U/min)", "Leerlaufstabilisierung Arbeitsbereich (121-135)",
    "Leerlaufstabilisierung Nullpunkt (80-125)", "Leerlaufstabilisierung Lastanpassung (123-137)", "Leerlaufstabilisierung Kennliniensteuerung (41-55)", 
    "Lambdaregelung aktiv (123-133 - nach 1,5 Min.)", "Lambdaregelung Anpassung (115-141)", "Zündwinkel (35-37 => 8-12° v.OT)"
]
max_points = 60

# -------- Zustandsvariablen --------
daten = [deque(maxlen=max_points) for _ in range(10)]
zeiten = deque(maxlen=max_points)
csv_daten = []
csv_dateiname = ""
ser = None
ani = None
frame_index = 0
linien = []
linien_gruppe = []
fig = None
axs = []
canvas = None
daten_puffer = deque(maxlen=300)
verbunden = False
start_aktiv = False
lese_thread_aktiv = False
werte = [0] * 10

# -------- GUI-Elemente --------
csv_slider = None
csv_slider_label = None
werte_labels = []

def verbinden():
    global ser, verbunden, start_aktiv, lese_thread_aktiv

    info_label.config(text="")

    if ser and ser.is_open:
        try:
            ser.close()
        except:
            pass

    try:
        port = get_selected_device()
        print(port)
        if port is None:
            meldung_zeigen("⚠️ Kein COM-Port ausgewählt", dauer=0)
            return

        print(f"🔌 Verbinde mit {port}...")
        ser = serial.Serial(port, 115200, timeout=2)
        time.sleep(2)  # warten auf automatischen Reset des Arduinos

        # Auf "READY" warten
        startzeit = time.time()
        empfangspuffer = ""
        bereit = False

        while time.time() - startzeit < 5:  # max. 5 Sekunden warten
            while ser.in_waiting:
                zeichen = ser.read().decode('utf-8', errors='ignore')
                empfangspuffer += zeichen
                if "READY" in empfangspuffer:
                    ser.write(b"<H>")
                    bereit = True
                    break
            if bereit:
                break

        if bereit:
            time.sleep(4)
            meldung_zeigen("✅ Verbunden und Arduino bereit", farbe="black")
            verbunden = True

            # Buttons aktivieren/deaktivieren
            button_verbinden.config(state="disabled")
            button_start.config(state="normal")
            button_stop.config(state="disabled")
        else:
            meldung_zeigen("⚠️ Keine Antwort vom Arduino (READY fehlt)", dauer=0)
            ser.close()
            verbunden = False

    except Exception as e:
        meldung_zeigen(f"❌ Verbindungsfehler: {e}", dauer=0)
        verbunden = False


def lesen_bis_ok(ser, erwartete_antwort, timeout=5):
    """Liest serielle Zeilen bis erwartete_antwort oder Timeout."""
    import time
    start_time = time.time()
    while True:
        if time.time() - start_time > timeout:
            print(f"❌ Timeout: '{erwartete_antwort}' nicht erhalten.")
            return False
        if ser.in_waiting > 0:
            zeile = ser.readline().decode(errors='ignore').strip()
            print(f"RX: {zeile}")
            if zeile == erwartete_antwort:
                return True
            
def start_datenempfang():
    global lese_thread_aktiv, start_aktiv, verbunden, modus
    if not verbunden:
        print("⚠️ Keine Verbindung")
        return
    try:
        ser.write(b"<S>")
        print("▶️ Startsignal gesendet, warte auf 'START OK'...")
        if lesen_bis_ok(ser, "START OK", timeout=10):
            lese_thread_aktiv = True
            threading.Thread(target=daten_lesen_thread, daemon=True).start()
            print("▶️ Datenempfang gestartet")
            start_aktiv = True
            start_livedaten()
            button_start.config(state="disabled")
            button_stop.config(state="normal")
        else:
            meldung_zeigen("❌ Start OK nicht erhalten, Start abgebrochen.")
    except Exception as e:
        meldung_zeigen(f"❌ Fehler beim Start: {e}")

def stop_datenempfang():
    try:
        ser.write(b"<X>")
        print("⏹ Stop-Signal gesendet, warte auf 'STOP OK'...")
    except Exception as e:
        meldung_zeigen(f"❌ Fehler beim Stoppen: {e}")
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

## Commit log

2025-06-28 button widerstaende auf 10k
    [diagnosegeraetKLinePlan.fzz]
2025-07-04 fehler im schaltplan korrigiert
    [diagnosegeraetKLinePlan.fzz]
2025-07-10 stl fuer alternativen Deckel
    [Deckel_200_20v.stl, Deckel_20v_Turbo.stl]
2025-07-10 bugfix bei mehrfachem ausblinken
    [diagnoseGeraet.ino]
2025-07-10 menuefuehrung kleinigkeiten
    [sensordaten_2025-07-10_221109.csv, sensordaten_2025-07-10_221136.csv]
2025-07-10 menuefuehrung kleinigkeiten und unnoetige kommentare entfernt
    [configuration.h]
